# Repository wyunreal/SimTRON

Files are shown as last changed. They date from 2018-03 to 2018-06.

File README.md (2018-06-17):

# SimTRON

MultiSim SMS device !

This repo contains source code and hardware specifications for building a 8 SIMs communications device to monitor SMS reception on up to 8 mobile lines.

# Hardware

The device is based on an Arduino PRO mini, running at 16 MHz and 5V. Board designed using Eagle Cad, sources under **hardware** folder.

## Schematic:

<p align="center" >
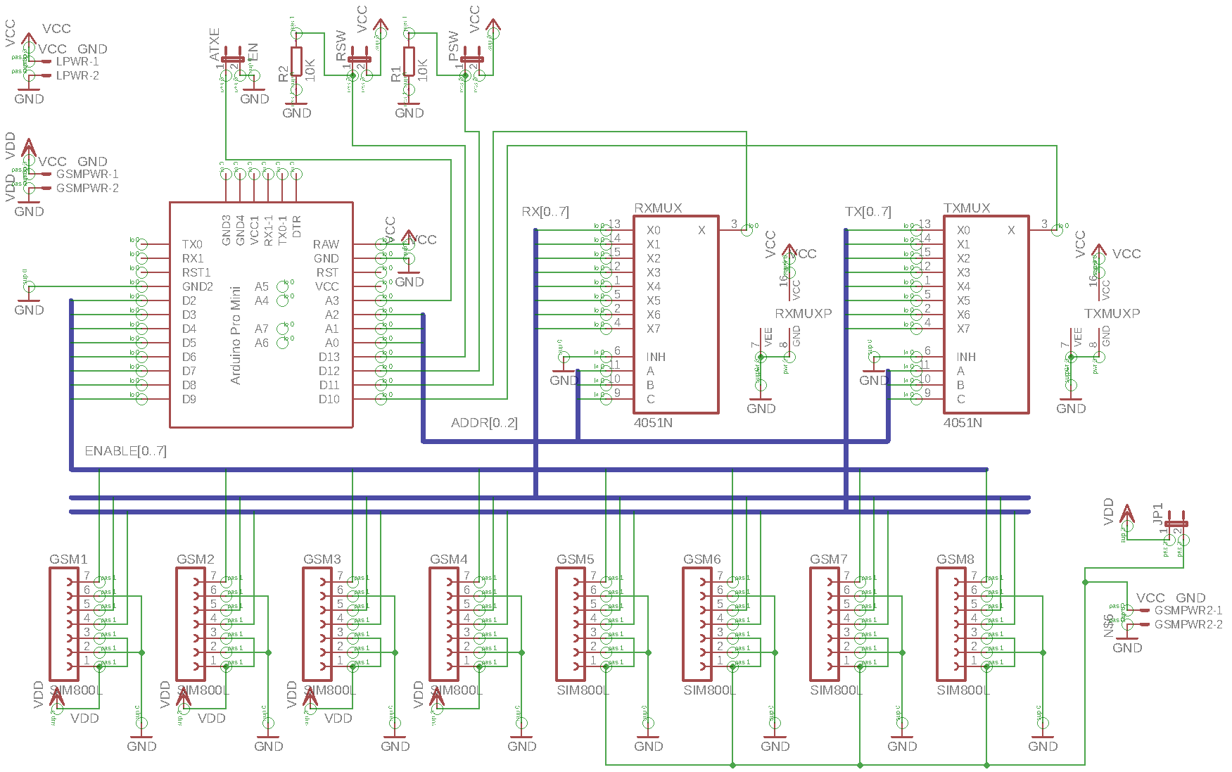
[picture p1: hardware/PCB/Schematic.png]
  
</p>

## Board:

<p align="center" >
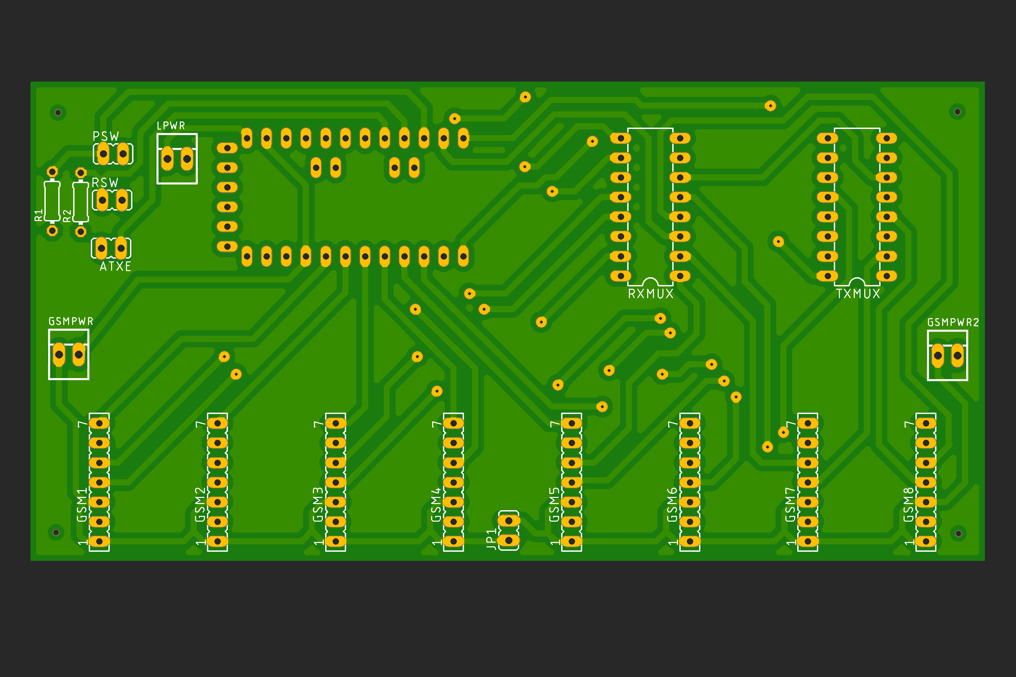
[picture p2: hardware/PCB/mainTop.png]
  
</p>

## Connections:

- **PSW:** power switch, connect the ATX power switch.
- **RSW:** reset switch, connect the ATX reset switch.
- **ATXE:** ATX enable signal, connect, from left to right: ATX Black (GND), ATX Green (Enable)
- **LPWR:** Logic power: connect, from left to right: ATX Purple (5V SB), ATX Black (GND)
- **GSMPWR:** GSM modules [1 to 4] power: connect, from left to right: ATX Red (5V), ATX Black (GND)
- **GSMPWR2:** GSM modules [5 to 8] power: connect, from left to right: Any alternative 5V poser supply (can be ATX Yellow (12V) through a 5V DC-DC step down, ATX Black (GND)
-- Take into account that you don't need to connect this power connector if you closes the JP1 jumper. In this case, all GSM modules will be powered through GSMPWR connector.
- **GSM[1..8]:** gsm modules, take into account polarity, reset pin on GSM module marked as 7 in board.

## List of materials

| Name | link | Unit price | Quantity | Total price |
|---|---|---|---|---|
| IC 74HC4051 | https://www.amazon.es/cd74hc4051e-Analog-Channel-CKT-16-Ti/dp/B01JV6VPJ8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 | 3.50 € | 1 | 3.50 € |
| GPRS SIm800L Modem | https://www.amazon.es/Sharplace-SIM800L-Tarjeta-Cuatribanda-QUAD-BAND/dp/B075D9ZYPW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 | 12.99 € | 8 | 103.92 € |
| Arduino Pro Mini 328P | https://www.amazon.es/Arduino-ATMEGA328-Avr328P-desarrollo-development/dp/B01DLPAAAK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 | 5 € | 1 | 5 € |
| FTDI USB Adapter | https://www.amazon.es/tinxi%C2%AE-FT232RL-adaptador-convertidor-Arduino/dp/B01C2P9GD2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 | 5.99 € | 1 | 5.99 € |
| Mini USB to Micro USB cable | https://www.amazon.es/Extensi%C3%B3n-Adaptador-Dispositivo-Charger-Converter/dp/B01MEDCEBJ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 | 7.99 € | 1 | 7.99 € |
| Raspberry PI Zero W Starter kit | https://www.amazon.es/PiHut-Zero-Essentials-Kit-Raspberry/dp/B06XCYGP27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 | 25 € | 1 | 25 € |
| Micro ATX enclosure | https://www.amazon.es/gp/product/B00TKP0E34/ref=oh_aui_detailpage_o01_s00?ie=UTF8&psc=1 | 46.95 € | 1 | 46.95 € |
| Manufactoring at China | https://www.pcbway.com/ | 10 € | 1 | 10 € |

Total price: 208.35 €

## Printed parts

<p align="center" >
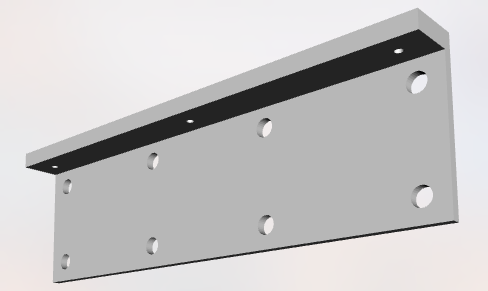
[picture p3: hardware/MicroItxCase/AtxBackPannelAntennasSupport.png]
  
</p>

This part has been designed to support the 8 Bnc antennas, fitting in any ATX case back side. You can print it with any 3D printer.

# Firmware

The firmware is under the **firmware** folder, you can use Arduino IDE to mod or add new features.

## Interface

The firmware uses **Serial** interface to communicate with host computer, the commands follows a simple text protocol, one command on each line and with following structure:

`commandOpCode param1 param2 param3`

Commands response are valid JSON objects.

### Available commands:

**Status command:**

`status channelNo`

Param: int, GSM channel number, 0 to 7

Response:

```javascript
{
  "type": "status",
  "channel": int, // the channel: 0 to 7
  "power": "string", // whether the ATX power is "on" or "off"
  "isEnabled": int, // whether the channel is enabled (1) or not (0)
  "icc": "string", // full ICC of the sim, if not sim inserted, empty icc will be returned
  "msisdn": "string", // full msisdn of the sim, if no sim inserted, empty msisdn will be returned, also, if unknown msisd, a question mark will be returned "?"
  "networkStatus": int, // 1 to 10, indicating the GSM network status of the channel
  "status": "string" // descriptive and printable message for networkStatus
}
```

**Catalog command:**

`catalog`

Response:

8 status objects, one per GSM channel (see status command)

**Enable command:**

`enable channelNo`

Param: int, GSM channel number, 0 to 7

Response:

Same response than status command.

**Disable command:**

`disable channelNo`

Param: int, GSM channel number, 0 to 7

Response:

Same response than status command.

**Send SMS command:**

`sendSms channelNo destinationMsisdn "SMS text"`

Params:
- int channelNo: GSM channel number, 0 to 7, this channel will be used as sender.
- string senderMsisdn: MSISDN to send to.
- string smsText: short text to send as SMS (max 130 chars)

Response:

if SMS sent correctly:

```javascript
{
  "type": "info",
  "body": "SMS sent"
}
```

if not:

```javascript
{
  "type": "error",
  "body": "Error sending SMS"
}
```

**Reset command:**

`reset`

Response:

No response, the system will reset and boot messages will be shown.

**Support command:**

`support`

Response:

```javascript
{
  "type": "support",
  "body": "Simtron v1.0.0 get support at https://github.com/wyunreal/simtron"
}
```

## Push messages

The device can send messages to the host computer without the needding of a command, these messages are:

**Boot started:**

```javascript
{
  "type": "booting",
  "body": "Booting Up ..."
}
```

**Boot completed:**

```javascript
{
  "type": "booting",
  "body": "System ready ..."
}
```

**SMS Received:**

```javascript
{
  "type": "sms",
  "channel": int, // the channel: 0 to 7, receiver of the SMS
  "icc": "string", // full ICC of the sim receiving the SMS
  "msisdn": "string", // full msisdn of the sim receiving the SMS, if unknown msisd, a question mark will be returned "?"
  "sender": "string", // sender MSISDN;
  "datetime": "string", // a date and time string, ready for presentation
  "body": "string" // SMS text
}
```

## Burning the firmware to Arduino Pro Mini

As the firmware enables the Watch Dog Timer, in order to being able using an Arduino Pro Mini, you need to burn the Arduino UNO bootloader first, this is completely safe as Arduino Pro Mini is a tiny but full featured version of the Arduino UNO.

Follow these instructions to burn the bootloader using another arduino as programmer:

https://www.luisllamas.es/usar-arduino-para-reprogramar-el-bootloader/

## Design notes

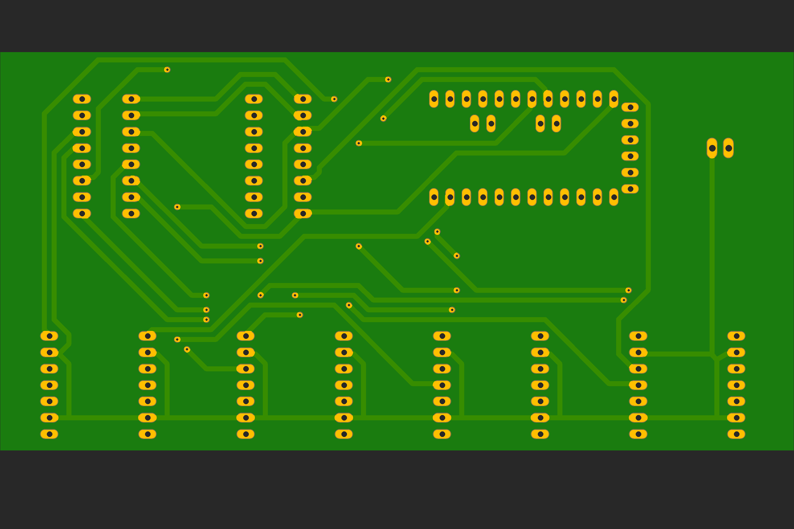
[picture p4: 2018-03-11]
hardware-temp/main-bottom.png

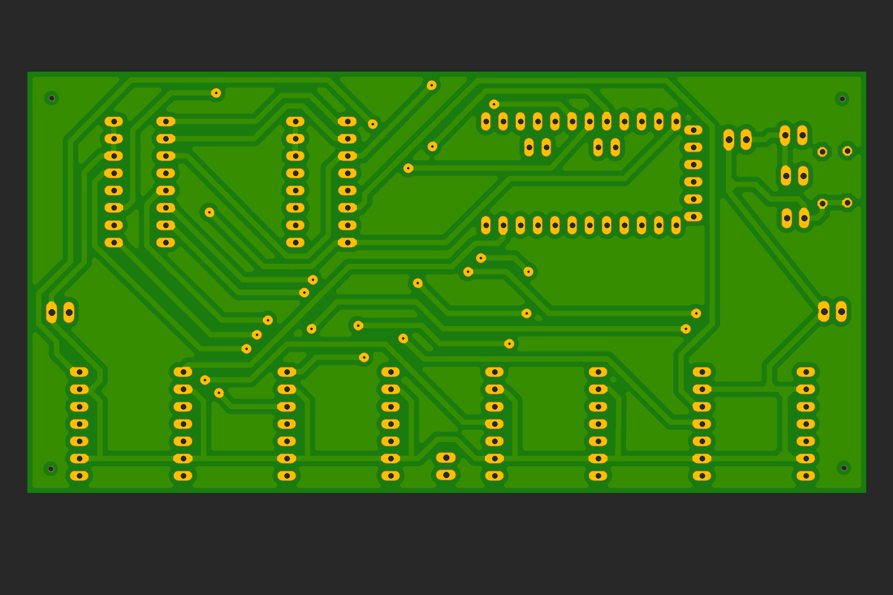
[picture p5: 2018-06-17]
hardware/PCB/mainBottom.png

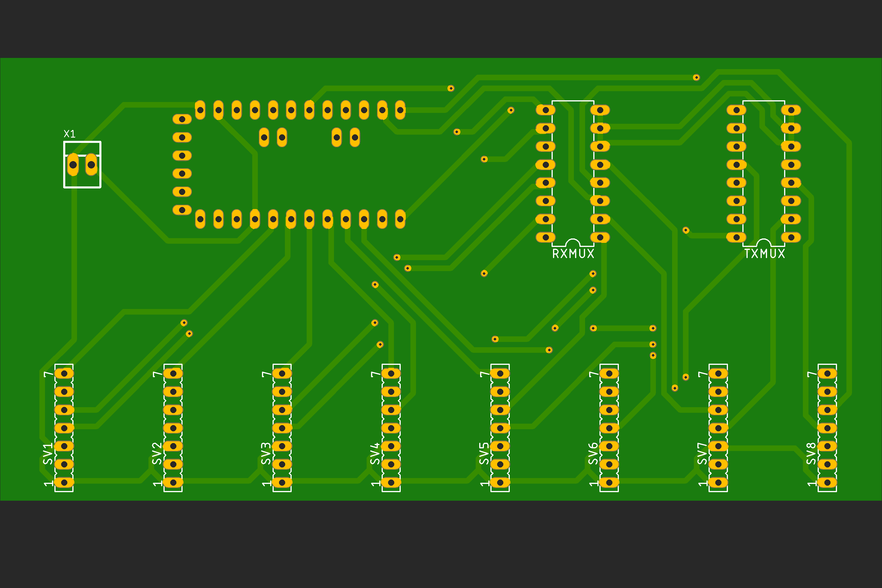
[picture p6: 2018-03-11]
hardware-temp/main-top.png

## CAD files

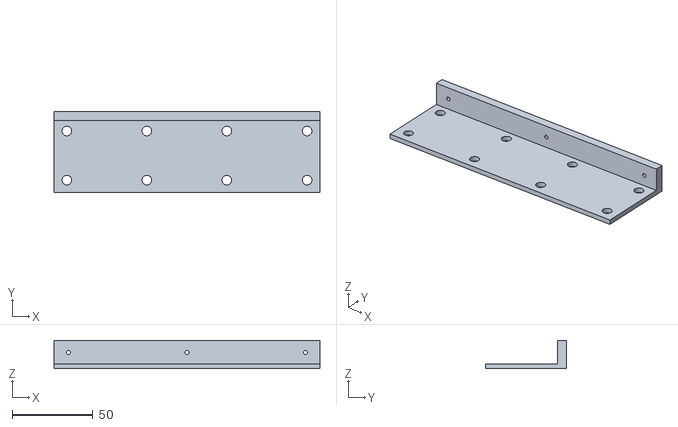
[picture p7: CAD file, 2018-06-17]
hardware/MicroItxCase/AtxBackPannelAntennasSupport.stl
165.0 x 50.0 x 17.5

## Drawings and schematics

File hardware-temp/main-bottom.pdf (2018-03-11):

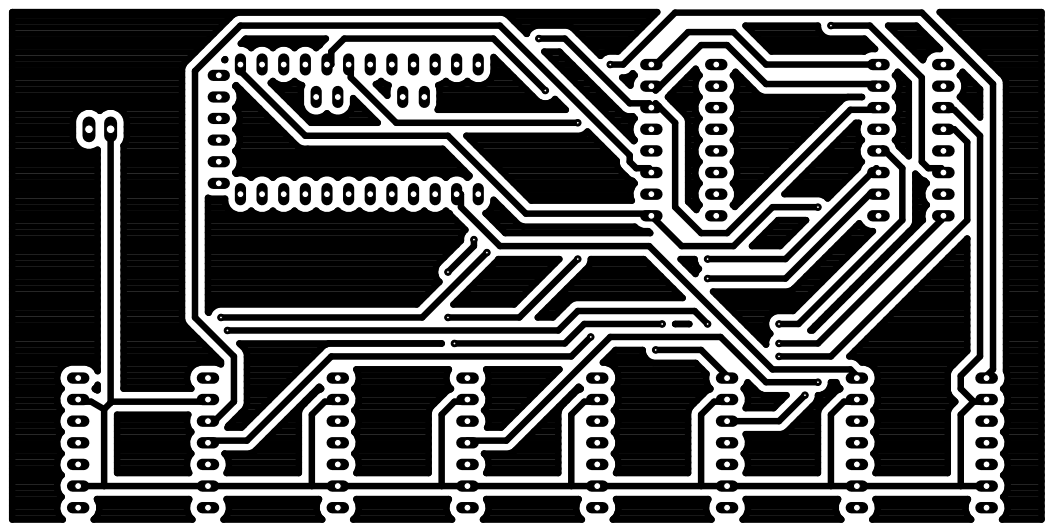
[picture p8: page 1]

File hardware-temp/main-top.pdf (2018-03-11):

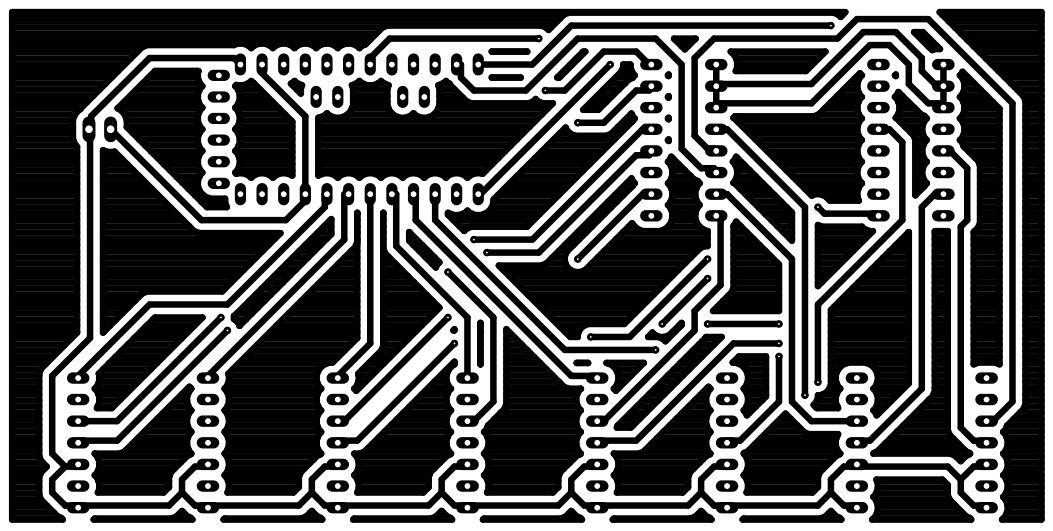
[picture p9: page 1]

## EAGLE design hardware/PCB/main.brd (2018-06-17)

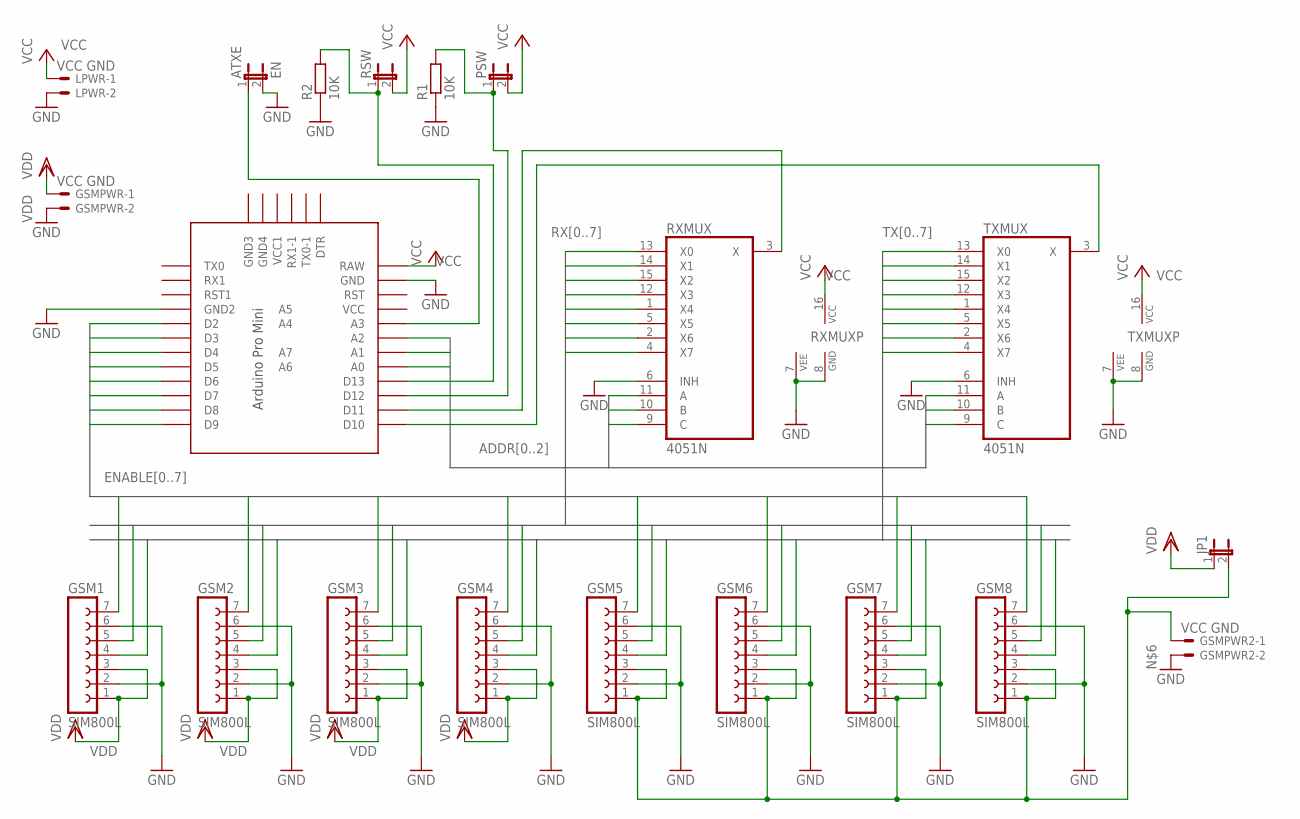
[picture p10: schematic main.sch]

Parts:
ARDUINO: PRO-MINI; PRO-MINI-2
ATXE: EN; JP1
GSM1, GSM2, GSM3, GSM4, GSM5, GSM6, GSM7, GSM8: SIM800L; FE07
GSMPWR, GSMPWR2: VCC GND; 22-23-2021
JP1: JP1
LPWR: VCC GND; 22-23-2021
PSW: JP1
R1, R2: 10K; 0204/7
RSW: JP1
RXMUX: 4051N; DIL16
TXMUX: 4051N; DIL16

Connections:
ADDR0: ARDUINO.A2, RXMUX.11 (A), TXMUX.11 (A)
ADDR1: ARDUINO.A1, RXMUX.10 (B), TXMUX.10 (B)
ADDR2: ARDUINO.A0, RXMUX.9 (C), TXMUX.9 (C)
ENABLE0: ARDUINO.D2, GSM1.7
ENABLE1: ARDUINO.D3, GSM2.7
ENABLE2: ARDUINO.D4, GSM3.7
ENABLE3: ARDUINO.D5, GSM4.7
ENABLE4: ARDUINO.D6, GSM5.7
ENABLE5: ARDUINO.D7, GSM6.7
ENABLE6: ARDUINO.D8, GSM7.7
ENABLE7: ARDUINO.D9, GSM8.7
GND: ARDUINO.GND, ARDUINO.GND1 (GND2), ATXE.2, GSM1.2, GSM1.6, GSM2.2, GSM2.6, GSM3.2, GSM3.6, GSM4.2, GSM4.6, GSM5.2, GSM5.6, GSM6.2, GSM6.6, GSM7.2, GSM7.6, GSM8.2, GSM8.6, GSMPWR.2, GSMPWR2.2, LPWR.2, R1.1, R2.1, RXMUX.6 (INH), RXMUX.7 (VEE), RXMUX.8 (GND), TXMUX.6 (INH), TXMUX.7 (VEE), TXMUX.8 (GND)
unnamed: ARDUINO.D11, RXMUX.3 (X)
unnamed: ARDUINO.D10, TXMUX.3 (X)
unnamed: ARDUINO.D13, R2.2, RSW.1
unnamed: GSM5.1, GSM5.3, GSM6.1, GSM6.3, GSM7.1, GSM7.3, GSM8.1, GSM8.3, GSMPWR2.1, JP1.2
unnamed: ARDUINO.A3, ATXE.1
unnamed: ARDUINO.D12, PSW.1, R1.2
RX0: GSM1.5, RXMUX.13 (X0)
RX1: GSM2.5, RXMUX.14 (X1)
RX2: GSM3.5, RXMUX.15 (X2)
RX3: GSM4.5, RXMUX.12 (X3)
RX4: GSM5.5, RXMUX.1 (X4)
RX5: GSM6.5, RXMUX.5 (X5)
RX6: GSM7.5, RXMUX.2 (X6)
RX7: GSM8.5, RXMUX.4 (X7)
TX0: GSM1.4, TXMUX.13 (X0)
TX1: GSM2.4, TXMUX.14 (X1)
TX2: GSM3.4, TXMUX.15 (X2)
TX3: GSM4.4, TXMUX.12 (X3)
TX4: GSM5.4, TXMUX.1 (X4)
TX5: GSM6.4, TXMUX.5 (X5)
TX6: GSM7.4, TXMUX.2 (X6)
TX7: GSM8.4, TXMUX.4 (X7)
VCC: ARDUINO.RAW, LPWR.1, PSW.2, RSW.2, RXMUX.16 (VCC), TXMUX.16 (VCC)
VDD: GSM1.1, GSM1.3, GSM2.1, GSM2.3, GSM3.1, GSM3.3, GSM4.1, GSM4.3, GSMPWR.1, JP1.1

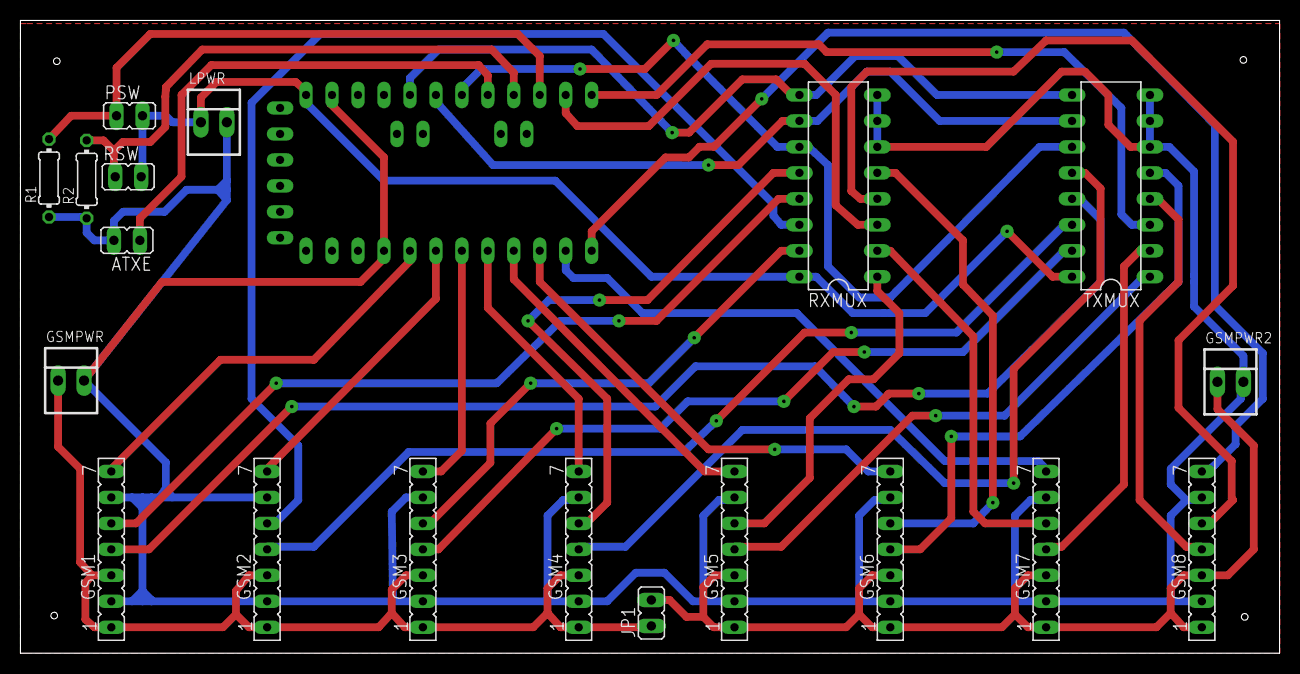
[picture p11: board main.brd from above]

Board: 2 copper layers, 123.2 x 61.9 mm, 20 parts (0 on the bottom side), 36 nets.

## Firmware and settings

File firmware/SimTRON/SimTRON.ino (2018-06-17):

#include <SoftwareSerial.h>
#include <Input.h>
#include <string.h>
#include <avr/wdt.h>

#define VERSION "1.0.0"

#define RX 10
#define TX 11

#define ATX_ENABLE A0
#define POWER_SW 12
#define RESET_SW 13
#define BUTTON_PRESSED_THRESHOLD 2

#define CHANNEL_COUNT 8
#define CHANNEL_S0 A1
#define CHANNEL_S1 A2
#define CHANNEL_S2 A3
#define SWITCH_CHANNEL_DELAY 50
#define STATUS_POLL_INTERVAL 2

#define MODEM_RESPONSE_MAX_CHARS 650
#define MAX_READ_RETRIES 25
#define NO_DATA_ON_READ_DELAY 10

#define FIRST_SMS_INDEX 1
#define SMS_PARSER_STATE_HEAD 1
#define SMS_PARSER_STATE_BODY 2
#define SMS_HEAD_SENDER 2
#define SMS_HEAD_DATE 3
#define SMS_HEAD_TIME 4

enum NetworkRegistrationStatus {
  NOT_REGISTERED = 0,
  REGISTERED_HOME = 1,
  SEARCHING = 2,
  REGISTRATION_DENIED = 3,
  UNKNOWN = 4,
  REGISTERED_ROAMING = 5,
  REGISTERED_HOME_SMS_ONLY = 6,
  REGISTERED_ROAMING_SMS_ONLY = 7,
  REGISTERED_FOR_EMERGENCY_ONLY = 8,
  REGISTERED_HOME_FOR_CSFB = 9,
  REGISTERED_ROAMING_FOR_CSFB = 10
};

struct ChannelStatusData {
  int channel;
  bool isEnabled;
  char msisdn[16];
  char icc[21];
  NetworkRegistrationStatus registrationStatus;
};

// power control
byte isPowerOn = true;
byte powerSwCount = 0;
byte resetSwCount = 0;

// Channels control
int channelEnablePin[] { 2, 3, 4, 5, 6, 7, 8, 9};
ChannelStatusData channelsStatus[8];
int selectedChannel = 0;

// Modules read
int simDataIndex = 0;
char simData[MODEM_RESPONSE_MAX_CHARS];

// SMS Parser
struct SmsData {
  int channel;
  char sender[16];
  char date[16];
  char time[16];
  char* body;
};
int smsParserState;
int headElementsPart;

SoftwareSerial sim(RX, TX);
Input input(50);

void doReset() {
  wdt_enable(WDTO_15MS);
  while(true);
}

void resetCommand(CommandParams &params, Stream &response) {
  doReset();
}

void supportCommand(CommandParams &params, Stream &response) {
  printSupportMessage();
}

void enableCommand(CommandParams &params, Stream &response) {
  int channel = params.getParamAsInt(0);
  if (channel >= 0 && channel < CHANNEL_COUNT) {
    ChannelStatusData* status = enableChannel(channel);
    printChannelStatusJson(status);
  }
}

void disableCommand(CommandParams &params, Stream &response) {
  int channel = params.getParamAsInt(0);
  if (channel >= 0 && channel < CHANNEL_COUNT) {
    ChannelStatusData* status = disableChannel(channel);
    printChannelStatusJson(status);
  }
}

void statusCommand(CommandParams &params, Stream &response) {
  int channel = params.getParamAsInt(0);
  if (channel >= 0 && channel < CHANNEL_COUNT) {
    readStatus(channel);
    printChannelStatusJson(&channelsStatus[channel]);
  }
}

void catalogCommand(CommandParams &params, Stream &response) {
  int currentlySelectedChannel = selectedChannel;
  for (int i = 0; i < CHANNEL_COUNT; i++) {
    readStatus(i);
    printChannelStatusJson(&channelsStatus[i]);
    wdt_reset();
  }
  selectedChannel = currentlySelectedChannel;
}

void readStatus(int channel) {
  selectChannel(channel);
  if (readIcc(channel)) {
    readMsisdn(channel);
    readNetworkStatus(channel);
  }
}

void sendSmsCommand(CommandParams &params, Stream &response) {
  int channel = params.getParamAsInt(0);
  if (channel >= 0 && channel < CHANNEL_COUNT) {
    char* msisdn = params.getParamAsString(1);
    char* sms = params.getParamAsString(2);
    selectChannel(channel);
    sendSmsToMsisdn(msisdn, sms);
  }
}

const InputCommand commandDefinitions[] PROGMEM = defineCommands(
  command("reset", 0, &resetCommand),
  command("support", 0, &supportCommand),
  command("enable", 1, &enableCommand),
  command("disable", 1, &disableCommand),
  command("status", 1, &statusCommand),
  command("catalog", 0, &catalogCommand),
  command("sendSms", 3, &sendSmsCommand)
);

void enablePower() {
  digitalWrite(ATX_ENABLE, LOW);
}

void disablePower() {
  digitalWrite(ATX_ENABLE, HIGH);
}

void setup() {
  wdt_disable();

  input.begin(9600, commandDefinitions);

  printBootingUpMessage();

  pinMode(POWER_SW, INPUT);
  pinMode(RESET_SW, INPUT);
  pinMode(ATX_ENABLE, OUTPUT);
  disablePower();
  delay(1000); // wait for ATX power stabilization
  enablePower();

  pinMode(CHANNEL_S0, OUTPUT);
  pinMode(CHANNEL_S1, OUTPUT);
  pinMode(CHANNEL_S2, OUTPUT);

  for (int i = 0; i < CHANNEL_COUNT; i++) {
    pinMode(channelEnablePin[i], OUTPUT);
    initChannel(i, false);
  }
  for (int i = 0; i < CHANNEL_COUNT; i++) {
    enableChannel(i);
    delay(1000); // wait for GSM boot up current peak
  }
  selectChannel(0);

  sim.begin(9600);

  wdt_enable(WDTO_8S);

  printBootCompleteMessage();
}

void updateButtonCounters(byte buttonPin, byte &counter) {
  if (digitalRead(buttonPin)) {
    counter++;
  } else {
    if (counter > 0) {
      counter--;
    }
  }
}

void checkPowerButtons() {
  updateButtonCounters(POWER_SW, powerSwCount);
  updateButtonCounters(RESET_SW, resetSwCount);
  if (powerSwCount >= BUTTON_PRESSED_THRESHOLD) {
    if (isPowerOn) {
      isPowerOn = false;
      disablePower();
    } else {
      isPowerOn = true;
      enablePower();
    }
  }
  if (resetSwCount >= BUTTON_PRESSED_THRESHOLD) {
    doReset();
  }
}

void loop() {
  if (isChannelEnabled(selectedChannel)) {
    if (readIcc(selectedChannel)) {
      readMsisdn(selectedChannel);
    }
    if (readSmsAtIndex(FIRST_SMS_INDEX)) {
      deleteSmsAtIndex(FIRST_SMS_INDEX);
    }
  }

  checkPowerButtons();

  selectNextChannel();

  wdt_reset();
}

ChannelStatusData* initChannel(int channel, bool enable) {
  channelsStatus[channel].channel = channel;
  resetChannelStatusData(channel);
  return enable ? enableChannel(channel) : disableChannel(channel);
}

ChannelStatusData* enableChannel(int channel) {
  digitalWrite(channelEnablePin[channel], HIGH);
  channelsStatus[channel].isEnabled = true;
  resetChannelStatusData(channel);
  return &channelsStatus[channel];
}

ChannelStatusData* disableChannel(int channel) {
  digitalWrite(channelEnablePin[channel], LOW);
  channelsStatus[channel].isEnabled = false;
  resetChannelStatusData(channel);
  return &channelsStatus[channel];
}

void resetChannelStatusData(int channel) {
  channelsStatus[channel].msisdn[0] = 0;
  channelsStatus[channel].icc[0] = 0;
  channelsStatus[channel].registrationStatus = UNKNOWN;
}

bool isChannelEnabled(int channel) {
  return channelsStatus[channel].isEnabled;
}

bool readIcc(int channel) {
  if (!isSimPresenceConfirmed(channel)) {
    sim.print(F("AT+CCID\r"));
    bool simPresent = readModemResponse(simData);
    if (simPresent) {
      return parseIcc(simData, channel);
    } else {
      return false;
    }
  } else {
    return true;
  }
}

bool isSimPresenceConfirmed(int channel) {
  return strlen(channelsStatus[channel].icc) > 0;
}

bool parseIcc(char* iccResponseData, int channel) {
  char* token = strtok (iccResponseData, "\r\n");
  while (token != NULL) {
    if (isValidIcc(token)) {
      if (strcmp(token, channelsStatus[channel].icc) != 0) {
        strcpy(channelsStatus[channel].icc, token);
      }
      return true;
    }
    token = strtok (NULL, "\r\n");
  }
  channelsStatus[channel].icc[0] = 0;
  return false;
}

bool isValidIcc(char* icc) {
  if (strlen(icc) >= 15) {
    while (icc[0] > 0) {
      if (icc[0] < 48 || (icc[0] > 57 && icc[0] != 'f' && icc[0] != 'F')) { // only 0..9, F or f chars
        return false;
      }
      icc++;
    }
    return true;
  } else {
    return false;
  }
}

void readMsisdn(int channel) {
  if (strlen(channelsStatus[channel].msisdn) == 0) {
    sim.print(F("AT+CNUM\r"));
    if (readModemResponse(simData)) {
      parseMsisdn(simData, channel);
    }
  }
}

void parseMsisdn(char* msisdnResponseData, int channel) {
  char* token = strtok (msisdnResponseData, "CNUM: ,\"\r\n");
  while (token != NULL) {
    if (isValidMsisdn(token)) {
      if (strcmp(token, channelsStatus[channel].msisdn) != 0) {
        strcpy(channelsStatus[channel].msisdn, token);
        return;
      }
    }
    token = strtok (NULL, "CNUM: ,\"\r\n");
  }
  strcpy(channelsStatus[channel].msisdn, "?");
}

bool isValidMsisdn(char* msisdn) {
  if (strlen(msisdn) > 5) {
    while (msisdn[0] > 0) {
      if ((msisdn[0] < 48 && msisdn[0] != 43) || msisdn[0] > 57) { // only 0..9 or '+' chars
        return false;
      }
      msisdn++;
    }
    return true;
  } else {
    return false;
  }
}

void readNetworkStatus(int channel) {
  sim.print(F("AT+CREG?\r"));
  bool statusReadCorrectly = readModemResponse(simData);
  if (statusReadCorrectly) {
    NetworkRegistrationStatus status = parseNetworkStatus(simData);
    if (status != UNKNOWN && status != channelsStatus[channel].registrationStatus) {
      channelsStatus[channel].registrationStatus = status;
    }
  } else {
    channelsStatus[channel].registrationStatus = UNKNOWN;
  }
}

NetworkRegistrationStatus parseNetworkStatus(char* networkStatusResponseData) {
  char* token = strtok (networkStatusResponseData, "\r\n");
  while (token != NULL) {
    if (strstr(token, "+CREG:") == token) {
      int networkStatus = token[9] - '0';
      if (networkStatus == 1 && token[10] == '0') {
        networkStatus = 10;
      }
      return networkStatus >= 1 && networkStatus <= 10 ? (NetworkRegistrationStatus)networkStatus : UNKNOWN;
    }
    token = strtok (NULL, "\r\n");
  }
  return UNKNOWN;
}

void sendSmsToMsisdn(const char* msisdn, const char* sms) {
  sim.write("AT+CMGF=1\r");
  bool statusReadCorrectly = readModemResponse(simData);
  if (!statusReadCorrectly) {
     printErrorSendingSmsMessage();
     return;
  }
  sim.write("AT+CMGS=\"");
  sim.write(msisdn);
  sim.write("\"\r");
  readModemResponse(simData);
  sim.write(sms);
  sim.write("\r");
  readModemResponse(simData);
  sim.write(0x1A);
  readModemResponse(simData);

  printSmsSentMessage();
}

bool readSmsAtIndex(int index) {
  sim.print(F("AT+CMGF=1\r"));
  bool modemInSmsMode = readModemResponse(simData);
  if (modemInSmsMode) {
    sim.print(F("AT+CMGR="));
    sim.print(index);
    sim.print("\r");
    bool readCommandSuccess = readModemResponse(simData);
    if(readCommandSuccess && strstr(simData, "\r\n+CMGR:") != NULL) {
      SmsData smsData;
      parseSms(simData, &smsData);
      printSmsJson(&smsData);
      return true;
    } else {
      return false;
    }
  }
}

void parseSms(char* smsText, SmsData* smsData) {
  smsData->channel = selectedChannel;
  headElementsPart = 0;
  smsParserState = SMS_PARSER_STATE_HEAD;
  char* token = strtok (smsText, "\",\r\n");
  while (token != NULL) {
    if (strlen(token) > 0) {
      if (smsParserState == SMS_PARSER_STATE_HEAD) {
        token = strtok (NULL, "\",\r\n");
        fillSmsHeadPart(headElementsPart, token, smsData);
        headElementsPart++;
        if (headElementsPart == 5) {
          smsParserState = SMS_PARSER_STATE_BODY;
        }
      } else {
        token = strtok (NULL, "\r\n");
        smsData->body = token;
        return;
      }
    }
  }
}

void fillSmsHeadPart(int headPartId, char* headPart, SmsData* smsData) {
  switch(headPartId) {
    case SMS_HEAD_SENDER:
      strcpy(smsData->sender, headPart);
      break;
    case SMS_HEAD_DATE:
      strcpy(smsData->date, headPart);
      break;
    case SMS_HEAD_TIME:
      strcpy(smsData->time, headPart);
      break;
  }
}

void deleteSmsAtIndex(int index) {
  sim.print(F("AT+CMGD="));
  sim.print(index);
  sim.print('\r');
  readModemResponse(simData);
}

bool readModemResponse(char* response) {
  bool successCodeRead = false;

  readUntilResultCode(response);
  if (strlen(simData) > 0) {
    successCodeRead = strstr(simData, "\r\nOK") != NULL;
  }

  return successCodeRead;
}

void readUntilResultCode(char* response) {
  int retries = 0;
  simDataIndex = 0;
  while((simDataIndex < MODEM_RESPONSE_MAX_CHARS - 1) && (sim.available() > 0 || retries < MAX_READ_RETRIES)) {
    if (sim.available()) {
      response[simDataIndex++] = sim.read();
    } else {
      delay(NO_DATA_ON_READ_DELAY);
      retries++;
    }
  }
  response[simDataIndex] = 0;
}

void selectNextChannel() {
  int channel = ++selectedChannel;
  if (channel >= CHANNEL_COUNT) {
    channel = 0;
  }
  selectChannel(channel);
}

void selectChannel(int channel) {
  digitalWrite(CHANNEL_S0, bitRead(channel,0));
  digitalWrite(CHANNEL_S1, bitRead(channel,1));
  digitalWrite(CHANNEL_S2, bitRead(channel,2));

  selectedChannel = channel;

  delay(SWITCH_CHANNEL_DELAY);
}

void printSmsJson(SmsData* smsData) {
  Serial.print(F("{\"type\": \"sms\""));
  Serial.print(F(", \"channel\": "));
  Serial.print(smsData->channel);
  Serial.print(F(", \"icc\": \""));
  Serial.print(channelsStatus[selectedChannel].icc);
  Serial.print(F("\", \"msisdn\": \""));
  Serial.print(channelsStatus[selectedChannel].msisdn);
  Serial.print(F("\", \"sender\": \""));
  printStringEscapingQuotes(smsData->sender);
  Serial.print(F("\", \"datetime\": \""));
  printStringEscapingQuotes(smsData->date);
  Serial.print(F(","));
  printStringEscapingQuotes(smsData->time);
  Serial.print(F("\", \"body\": \""));
  printStringEscapingQuotes(smsData->body);
  Serial.println(F("\"}"));
}

void printStringEscapingQuotes(char* str) {
  while (str[0] != 0) {
    if (str[0] == '"') {
      Serial.print("\\");
    }
    Serial.print(str[0]);
    str++;
  }
}

void printChannelStatusJson(ChannelStatusData* statusData) {
  Serial.print(F("{\"type\": \""));
  Serial.print(F("status"));
  Serial.print(F("\", \"channel\": "));
  Serial.print(statusData->channel);
  Serial.print(F(", \"power\": \""));
  Serial.print(isPowerOn ? F("on") : F("off"));
  Serial.print(F("\", \"isEnabled\": "));
  Serial.print(statusData->isEnabled);
  Serial.print(F(", \"icc\": \""));
  Serial.print(statusData->icc);
  Serial.print(F("\", \"msisdn\": \""));
  Serial.print(statusData->msisdn);
  Serial.print(F("\", \"networkStatus\": "));
  Serial.print(statusData->registrationStatus);
  Serial.print(F(", \"status\": \""));
  if (statusData->isEnabled) {
    if (strlen(statusData->icc) > 0) {
      Serial.print(F("Channel enabled, SIM present, "));
      switch (statusData->registrationStatus) {
        case NOT_REGISTERED:
          Serial.print(F("Not registered"));
          break;
        case REGISTERED_HOME:
          Serial.print(F("Registered in home network"));
          break;
        case SEARCHING:
          Serial.print(F("Searching network"));
          break;
        case REGISTRATION_DENIED:
          Serial.print(F("Registration denied"));
          break;
        case UNKNOWN:
          Serial.print(F("Unknown registration status"));
          break;
        case REGISTERED_ROAMING:
          Serial.print(F("Registered in roaming"));
          break;
        case REGISTERED_HOME_SMS_ONLY:
          Serial.print(F("Registered in home network for SMS only"));
          break;
        case REGISTERED_ROAMING_SMS_ONLY:
          Serial.print(F("Registered in roaming for SMS only"));
          break;
        case REGISTERED_FOR_EMERGENCY_ONLY:
          Serial.print(F("Registered for emergency use only"));
          break;
        case REGISTERED_HOME_FOR_CSFB:
          Serial.print(F("Registered in home network for CSFB"));
          break;
        case REGISTERED_ROAMING_FOR_CSFB:
          Serial.print(F("Registered in roaming for CSFB"));
          break;
      };
    } else {
      Serial.print(F("Channel enabled, SIM not present"));
    }
  } else {
    Serial.print(F("Channel disabled"));
  }
  Serial.println(F("\"}"));
}

void printBootingUpMessage() {
  Serial.println(F("{\"type\": \"booting\", \"body\": \"Booting Up ...\"}"));
}

void printBootCompleteMessage() {
  Serial.println(F("{\"type\": \"booting\", \"body\": \"System ready...\"}"));
}

void printErrorSendingSmsMessage() {
  Serial.println(F("{\"type\": \"error\", \"body\": \"Error sending SMS\"}"));
}

void printSmsSentMessage() {
  Serial.println(F("{\"type\": \"info\", \"body\": \"SMS sent\"}"));
}

void printSupportMessage() {
  Serial.print(F("{\"type\": \"support\", \"body\": \""));
  Serial.print(F("Simtron v"));
  Serial.print(F(VERSION));
  Serial.print(F(" get support at https://github.com/wyunreal/simtron"));
  Serial.println(F("\"}"));
}

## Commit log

2018-03-09 fixing some json syntax errors
    [SimTRON.ino]
2018-03-11 Adding board design (eagle project)
    [main.brd, main.sch]
2018-03-11 moving hardware to new folder
    [main.brd, main.sch]
2018-03-11 moving hardware to definitive folder
    [main.brd, main.sch]
2018-03-20 fix couple issues related to ICC parsing
    [SimTRON.ino]
2018-03-31 some error checking and secure programming on the furmware
    [SimTRON.ino]
2018-05-27 doing some fixes on the hardware, increasing vias size and removing DRC errors
    [copper_bottom.gbr, copper_top.gbr, drills.xln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]
2018-05-31 adding reset command and sendSMS command
    [SimTRON.ino]
2018-06-16 adding ATX control electronics
    [main.brd]
2018-06-17 adding power management to arduino sketch
2018-06-17 adding extra power supply for GSM, and connecting to gsm power through a jumper
    [main.brd, main.sch]
2018-06-17 moving around hard
    [main.brd, main.sch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]
2018-06-17 fixing case issue in hardware folder
    [main.brd, main.sch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]
2018-06-17 adding printed atx case parts
    [AtxBackPannelAntennasSupport.stl, main.brd, main.sch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]
